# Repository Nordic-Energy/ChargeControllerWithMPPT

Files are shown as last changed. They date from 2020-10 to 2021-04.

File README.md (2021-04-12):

## Solar charge controller with MPPT algorithm

The charge controller is controlled by a dedicated STM32F334C8T6 microcontroller with a High Resolution PWM (HRPWM) on board. The use of this device is possible a devkit for studying the algorithms for finding the maximum power point (TMM) and as a device for working in an solar power plant with a capacity of up to 500 W.

Photo of MPPT

>

Photo of MPPT

When developing a charge controller the main emphasis is on creating reliable hardware using the best components and on implementing the most efficient TMM search algorithms. There are no electrolytic capacitors in the controller, instead of them solid polymer capacitors with an increased service life are used and as well as the thermal modes of operation of the device are optimized. That together will provide a guaranteed service life of at least 10 years. This will increase the reliability of autonomous mini-power plants and reduce equipment maintenance costs.

## Features:

* Use 32-bit ARM MCU STM32F334C8 with HRPWM
* Voltage input: *15...60V*
* Voltage output: *12/24V*
* Max charge current: *20A*
* Conversion frequency: *100kHz*
* Efficiency: *>94%*
* MPPT algorithm
* Type battery: *SLA, AGM, GEL, Li-ion, LiFePo4, LTO*
* Interface: *CAN, Wi-Fi*

## Built-in protection:
* Overvoltage
* Undervoltage
* Overcurrent
* Overheat
* PV short circuit
* PV reverse polarity
* Battery reverse polarity

## Project structure:

* *docs* - documentation for project: ВОМ, schematic, etc
* *hardware* - source project for design PCB
* *manufacture* - gerber files for order PCB
* *mechanical* - source project for 3D design

## Firmware

* [Universal firmware project for MPPT solar charge](https://github.com/RedCommissary/mppt-charger-firmware)
* [Project HMI TFT display panel for controller](https://github.com/RedCommissary/display-tft-3.5)

## License

All source files for the project are distributed under the [MIT](./LICENSE "Text license") license and you can use the project for commercial activities. But you need remembering that the author of the project does not give any guarantees for the operability of the device or parts of the project and also does not bear no liability for claims or damages.

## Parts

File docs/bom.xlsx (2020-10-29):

Designator | Value | PartNumber | Manufacturer | Quantity | Comment | HelpURL
C1, C6, C11, C14, C15, C22, C28, C34, C36, C38, C39, C40, C41, C44, C45, C49 | 0.1μF | CL10B104KB8WPND | Samsung | 16 | Ceramic capacitor, 0.1μF, X7R, ±10%, 50V, 603, -55...+125°C | https://www.digikey.com/product-detail/en/samsung-electro-mechanics/CL10B104KB8WPND/1276-CL10B104KB8WPNDCT-ND/11488014
C2 | 2.7pF | CL10C2R7CB81PNC | Samsung | 1 | Ceramic capacitor, 2.7pF, NPO, ±0.25pF, 50V, 603, -55...+125°C | https://www.digikey.com/product-detail/en/samsung-electro-mechanics/CL10C2R7CB81PNC/1276-6554-1-ND/5961413
C3 | 4.7pF | CL10C4R7BB8NNNC | Samsung | 1 | Ceramic capacitor, 4.7pF, NPO, ±0.1pF, 50V, 603, -55...+125°C | https://www.digikey.com/product-detail/en/samsung-electro-mechanics/CL10C4R7BB8NNNC/1276-1792-1-ND/3889878
C4, C5, C13, C35, C37, C43 | 4.7μF | CL10B475KQ8NQNC | Samsung | 6 | Ceramic capacitor, 4.7μF, X7R, ±10%, 6.3V, 603, -55...+125°C | https://www.digikey.com/en/products/detail/samsung-electro-mechanics/CL10B475KQ8NQNC/3887745
C7, C23, C29, C31, C33, C42 | 0.01μF | CL10B103KB8NNNC | Samsung | 6 | Ceramic capacitor, 0.01μF, X7R, ±10%, 50V, 603, -55...+125°C | https://www.digikey.com/product-detail/en/samsung-electro-mechanics/CL10B103KB8NNNC/1276-1009-1-ND/3889095
C8 | 2.2μF | CL32B225KCJSNNE | Samsung | 1 | Ceramic capacitor, 2.2μF, X7R, ±10%, 100V, 1210, -55...+125°C | https://www.digikey.com/en/products/detail/samsung-electro-mechanics/CL32B225KCJSNNE/3889020
C9, C12, C48 | 1μF | CL10B105KA8NNNC | Samsung | 3 | Ceramic capacitor, 1μF, X7R, ±10%, 25V, 603, -55...+125°C | https://www.digikey.com/product-detail/en/samsung-electro-mechanics/CL10B105KA8NNNC/1276-1184-1-ND/3889270
C10 | 22μF | CL32B226KOJNNNE | Samsung | 1 | Ceramic capacitor, 22μF, X7R, ±10%, 16V, 1210, -55...+125°C | https://www.digikey.com/en/products/detail/samsung-electro-mechanics/CL32B226KOJNNNE/3887513
C16 | 0.47μF | CL21B474KAFNNNG | Samsung | 1 | Ceramic capacitor, 0.47μF, X7R, ±10%, 25V, 805, -55...+125°C | https://www.digikey.com/product-detail/en/samsung-electro-mechanics/CL21B474KAFNNNG/1276-6480-1-ND/5958108
C17 | 2.2μF | CL21B225KAFNFNE | Samsung | 1 | Ceramic capacitor, 2.2μF, X7R, ±10%, 25V, 805, -55...+125°C | https://www.digikey.com/product-detail/en/samsung-electro-mechanics/CL21B225KAFNFNE/1276-2953-1-ND/3891039
C18, C19, C20, C21 | 330μF | 35SEK330M | Panasonic | 4 | Solid polymer capacitor, 330μF, 35V, ±20%, 18mOhm, 13x10x5 mm, -55...+105°C | https://www.digikey.com/product-detail/en/panasonic-electronic-components/35SEK330M/P122629-ND/8030545
C24, C25, C26, C27 | 68μF | 63SXE68M | Panasonic | 4 | Solid polymer capacitor, 68μF, 63V, ±20%, 25mOhm, 13x10x5 mm, -55...+105°C | https://www.digikey.com/products/en?keywords=63SXE68M
C30, C32 | 220pF | CL10B221KB8NFNC | Samsung | 2 | Ceramic capacitor, 220pF, X7R, ±10%, 50V, 603, -55...+125°C | https://www.digikey.com/product-detail/en/samsung-electro-mechanics/CL10B221KB8NFNC/1276-1986-1-ND/3890072
C46, C47 | 12pF | CL10C120JB8NNNC | Samsung | 2 | Ceramic capacitor, 12pF, NPO, ±10%, 50V, 603, -55...+125°C | https://www.digikey.com/product-detail/en/samsung-electro-mechanics/CL10C120JB8NNNC/1276-1254-1-ND/3889340
D1 |  | ESP32-PICO-D4 | Espressif Systems | 1 | IC RF transceiver, 802.11b/g/n + Bluetooth v4.2, 2.4GHz, 32-Bit, Xtensa LX6, 4Mb, 520KB, 2.7...3.6V, -40...+85°C, 48-LGA | https://www.digikey.com/product-detail/en/espressif-systems/ESP32-PICO-D4/1904-1029-1-ND/9381738
D2 |  | LM5017SD/NOPB | Texas Instruments | 1 | DC/DC buck converter, input 7.5...100V, 1MHz, output 1.225...90V, 0.6A, -40...+125°C, 8-WSON | https://www.digikey.com/product-detail/en/texas-instruments/LM5017SD-NOPB/LM5017SD-NOPBCT-ND/3137455
D3 |  | AP63200WU-7 | Diodes | 1 | DC/DC buck converter, input 3.8...32V, 500kHz, output 1.2...12V, 2A, -40...+85°C, SOT23-6 | https://www.digikey.com/en/products/detail/diodes-incorporated/AP63200WU-7/9858423
D4 |  | NCP5183DR2G | ON Semiconductor | 1 | Half-bridge gate driver, 600V, 500kHz, ±4.3A, supply 9...18V, -40...+125°C, 8-SOIC | https://www.digikey.com/product-detail/en/on-semiconductor/NCP5183DR2G/NCP5183DR2GOSCT-ND/7066807
D5, D6 |  | TSV991ILT | STMicroelectronics | 2 | IC op amplifier, Rail-to-Rail, 20 MHz, 2.7...5.5V, -40...+125°C, SOT23-5 | https://www.digikey.com/product-detail/en/stmicroelectronics/TSV991ILT/497-6001-1-ND/1578484
D7 |  | STM32F334C4T6 | STMicroelectronics | 1 | IC microcontroller, 32-Bit, Cortex-M4, 72MHz, 16KB, 12KB, 2...3.6V, -40...+85°C, 48-LQFP | https://www.digikey.com/en/products/detail/stmicroelectronics/STM32F334C4T6/4989170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
D8 |  | 24AA01T-I/OT | Microchip Technology | 1 | IC memory, EEPROM, 1KB (128x8), 400 kHz, I2C, 1.7...5.5V, -40...+85°C, SOT-23-5 | https://www.digikey.com/product-detail/en/microchip-technology/24AA01T-I-OT/24AA01T-I-OTCT-ND/857670
D9 |  | SN65HVD231DR | Texas Instruments | 1 | IC CAN transceiver, 1Mbps, Half-duplex, 3...3.6V, -40...+85°C, 8-SOIC | https://www.digikey.com/product-detail/en/texas-instruments/SN65HVD231DR/296-26343-1-ND/2254977
L1 | 1.6nH | LQW18AS1N6J0ZD | Murata Electronics | 1 | Fixed inductor, 1.6nH, ±5%, 603, 700mA, -55...+125°C | https://www.digikey.com/product-detail/en/murata-electronics/LQW18AS1N6J0ZD/490-15806-1-ND/6800471
L2 | 220μH | SDR0805-221KL | Bourns | 1 | Fixed inductor, 220μH, ±10%, SDR0805, 490mA, -40...+125°C | https://www.digikey.com/product-detail/en/bourns-inc/SDR0805-221KL/SDR0805-221KLCT-ND/2127164
L3 | 4.7μH | CD32YP0302-4R7M | YJYCOIN | 1 | Fixed inductor, 4.7μH, ±20%, CD32 series, 1.5A, -40...+125°C | https://lcsc.com/product-detail/New-Arrivals_YJYCOIN-CD32YP0302-4R7M_C492259.html
L4 | 40μH | 0077548A7 | Magnetics | 1 | Fixed inductor, 40μH, ±10%, R32.8/20.1/10.7, Kool Mu, µ=125, 127 нГн/витков2 | http://ferrite.ru/warehouse/r-32-820-110-7-77548-a7.html
L5 | 10μH | LQM18FN100M00D | Murata Electronics | 1 | Fixed inductor, 10μH, ±20%, 603, 50mA, -55...+125°C | https://www.digikey.com/product-detail/en/murata-electronics-north-america/LQM18FN100M00D/490-4025-1-ND/1016285
R1, R2, R5, R8, R9, R12, R16, R17, R21, R22, R24, R28, R33, R34, R48, R50, R52 | 10k | AC0603FR-0710KL | Yageo | 17 | Resistor film, 10k, ±1%, 603, 0.1W, -55...+125°C | https://www.digikey.com/en/products/detail/yageo/AC0603FR-0710KL/2827814
R3 | 499k | RC0603FR-07499KL | Yageo | 1 | Resistor film, 499k, ±1%, 603, 0.1W, -55...+125°C | https://www.digikey.com/en/products/detail/yageo/RC0603FR-07499KL/727267
R4 | 91k | RC0603FR-0791KL | Yageo | 1 | Resistor film, 91k, ±1%, 603, 0.1W, -55...+125°C | https://www.digikey.com/en/products/detail/yageo/RC0603FR-0791KL/727428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
R6, R31, R32, R37, R40, R43, R45, R46, R47, R54, R55, R57, R58, R60, R61, R63, R64 | 1k | RC0603FR-071KL | Yageo | 17 | Resistor film, 1k, ±1%, 603, 0.1W, -55...+125°C | https://www.digikey.com/product-detail/en/yageo/RC0603FR-071KL/311-1-00KHRCT-ND/729790
R7 | 88k7 | RC0603FR-0788K7L | Yageo | 1 | Resistor film, 88k7, ±1%, 603, 0.1W, -55...+125°C | https://www.digikey.com/en/products/detail/yageo/RC0603FR-0788K7L/727415
R11 | 30k9 | RC0603FR-0730K9L | Yageo | 1 | Resistor film, 30k9, ±1%, 603, 0.1W, -55...+125°C | https://www.digikey.com/en/products/detail/yageo/RC0603FR-0730K9L/727144
R13, R15 | 2R4 | RC0805JR-072R4L | Yageo | 2 | Resistor film, 2R4, ±5%, 805, 0.125W, -55...+125°C | https://www.digikey.com/product-detail/en/yageo/RC0805JR-072R4L/311-2.4ARCT-ND/731220
R14, R19, R26 | 10k | RC0805JR-0710KL | Yageo | 3 | Resistor film, 10k, ±5%, 805, 0.125W, -55...+125°C | https://www.digikey.com/product-detail/en/yageo/RC0805JR-0710KL/311-10KARCT-ND/731188
R18 | 39k | RC0603FR-0739KL | Yageo | 1 | Resistor film, 39k, ±1%, 603, 0.1W, -55...+125°C | https://www.digikey.com/en/products/detail/yageo/RC0603FR-0739KL/727195
R20, R23, R27, R35, R41, R49, R51, R53, R56, R59, R62 | 120R | RC0603JR-07120RL | Yageo | 11 | Resistor film, 120R, ±5%, 603, 0.1W, -55...+125°C | https://www.digikey.com/product-detail/en/yageo/RC0603JR-07120RL/311-120GRCT-ND/729653
R25 | 100k | RC0805FR-07100KL | Yageo | 1 | Resistor film, 100k, ±1%, 805, 0.125W, -55...+125°C | https://www.digikey.com/product-detail/en/yageo/RC0805FR-07100KL/311-100KCRCT-ND/730491
R29 | 5k1 | RC0603FR-075K1L | Yageo | 1 | Resistor film, 5k1, ±1%, 603, 0.1W, -55...+125°C | https://www.digikey.com/en/products/detail/yageo/RC0603FR-075K1L/727268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
R30, R38, R39, R44 | 75k | AC0603FR-0775KL | Yageo | 4 | Resistor film, 75k, ±1%, 603, 0.1W, -55...+125°C | https://www.digikey.com/en/products/detail/yageo/AC0603FR-0775KL/5896284
R36, R42 | 0R002 | PA2512FKM7W0R002E | Yageo | 2 | Resistor film, 0R002, ±1%, 2512, 2W, -55...+170°C | https://www.digikey.com/en/products/detail/yageo/PA2512FKM7W0R002E/9696342
SB1 |  | PTS636 SM43 | C&K | 1 | Tactile button, 6x3.5mm | https://www.digikey.com/product-detail/en/c-k/PTS636-SM43-SMTR-LFS/CKN12310-1-ND/10071745
VD1, VD5 |  | MBR2H100SFT3G | ON Semiconductor | 2 | Schottky diode, 100V, 2A, 840mV, 15pF, SOD-123F, -55...+150°C | https://www.digikey.com/product-detail/en/on-semiconductor/MBR2H100SFT3G/MBR2H100SFT3GOSCT-ND/3462288
VD2, VD3, VD7 |  | 150060VS75000 | Wurth | 3 | LED, 20mA, 2V, 603, -55...+150°C | https://www.digikey.com/product-detail/en/w-rth-elektronik/150060VS75000/732-4980-1-ND/4489904
VD6 |  | MMSZ5245BT1G | ON Semiconductor | 1 | Zener diode, 16V, 500mW, 0.9V, 16Ohm, SOD-123, -55...+150°C | https://www.digikey.com/product-detail/en/on-semiconductor/MMSZ5245BT1G/MMSZ5245BT1GOSCT-ND/1139899
VD8, VD11, VD13, VD14, VD15 |  | 150060RS75000 | Wurth | 5 | LED, 20 mA, 2V, 603, -55...+150°C | https://www.digikey.com/product-detail/en/w-rth-elektronik/150060RS75000/732-4978-1-ND/4489899
VD9 |  | ESDCAN06-2BLY | STMicroelectronics | 1 | TVS diode, 24V, 230W peak, 3A, 13pF, SOT-23, -40...+150°C | https://www.digikey.com/product-detail/en/stmicroelectronics/ESDCAN06-2BLY/497-19090-1-ND/10057130
VD10 |  | 150060BS75000 | Wurth | 1 | LED, 20mA, 3.2V, 603, -55...+150°C | https://www.digikey.com/product-detail/en/w-rth-elektronik/150060BS75000/732-4966-1-ND/4489893
VD12 |  | 150060YS75000 | Wurth | 1 | LED, 20mA, 2V, 603, -55...+150°C | https://www.digikey.com/product-detail/en/wurth-electronics-inc/150060YS75000/732-4981-1-ND/4489907
VT1, VT2, VT4, VT6 |  | IPP086N10N3GXKSA1 | Infineon Technologies | 4 | MOSFET N-channel transistor, 100V, 80A, 55nC, 125W, 8.6mOhm, 3980pF, TO-220, -55...+150°C | https://www.digikey.com/en/products/detail/infineon-technologies/IPP086N10N3GXKSA1/2081155
VT3 |  | IRLML0030TRPBF | Infineon Technologies | 1 | MOSFET N-channel transistor, 30V, 5.3A, 2.6nC, 1.3W, 27mOhm, 382pF, SOT-23, -55...+150°C | https://www.digikey.com/product-detail/en/infineon-technologies/IRLML0030TRPBF/IRLML0030TRPBFCT-ND/2202231
VT5 |  | BSS315PH6327XTSA1 | Infineon Technologies | 1 | MOSFET P-channel transistor, 30V, 1.5A, 2.3nC, 500mW, 150mOhm, 282pF, SOT-23, -55...+150°C | https://www.digikey.com/en/products/detail/infineon-technologies/BSS315PH6327XTSA1/2783468
VT7 |  | BC847CLT1G | ON Semiconductor | 1 | NPN transistor, 45V, 100mA, 100MHz, 300mW, 0.6V, 420, SOT-23, -55...+125°C | https://www.digikey.com/product-detail/en/on-semiconductor/BC847CLT1G/BC847CLT1GOSCT-ND/917836
X1 |  | SM06B-GHS | JST | 1 | Connector, 6pin, 1.25mm, 50VDC, 1A | https://www.digikey.com/product-detail/en/jst-sales-america-inc/SM06B-GHS-TB-LF-SN/455-1568-1-ND/807836
X2 |  | U.FL-R-SMT(01) | Hirose Electric | 1 | Connector u.FL, 50 Ohm, 6GHz | https://www.digikey.com/product-detail/en/hirose-electric-co-ltd/U.FL-R-SMT-01/H9161-ND/513010
X3, X4 |  | XT60PW-M | AMASS | 2 | Power connector, 2pin, 7.2mm, 500V, 60A | https://lcsc.com/product-detail/Connectors_Changzhou-Amass-Elec-XT60PW-M_C98732.html
X5, X6 |  | CWF-2 | Connfly | 2 | Connector, 2pin, 2.54mm, 250VAC, 3A | https://www.chipdip.ru/product/cwf-2
X7 |  | SM05B-GHS | JST | 1 | Connector, 5pin, 1.25mm, 50VDC, 1A | https://www.digikey.com/product-detail/en/jst-sales-america-inc/SM05B-GHS-TB-LF-SN/455-1567-1-ND/807835
X8 |  | CWF-4 | Connfly | 1 | Connector, 4pin, 2.54mm, 250VAC, 3A | https://www.chipdip.ru/product/cwf-4
X9 |  | 615008137421 | Wurth | 1 | Etherner RJ-45 connector | https://www.digikey.com/product-detail/en/w-rth-elektronik/615008137421/732-2112-ND/2060608
Z1 |  | ECS-80-12-33-JGN-TR | ECS | 1 | Crystal, 8MHz, 12pF, ±30ppm, case 3225, -40...+85°C | https://www.digikey.com/product-detail/en/ecs-inc/ECS-80-12-33-JGN-TR/50-ECS-80-12-33-JGN-CT-ND/10478769

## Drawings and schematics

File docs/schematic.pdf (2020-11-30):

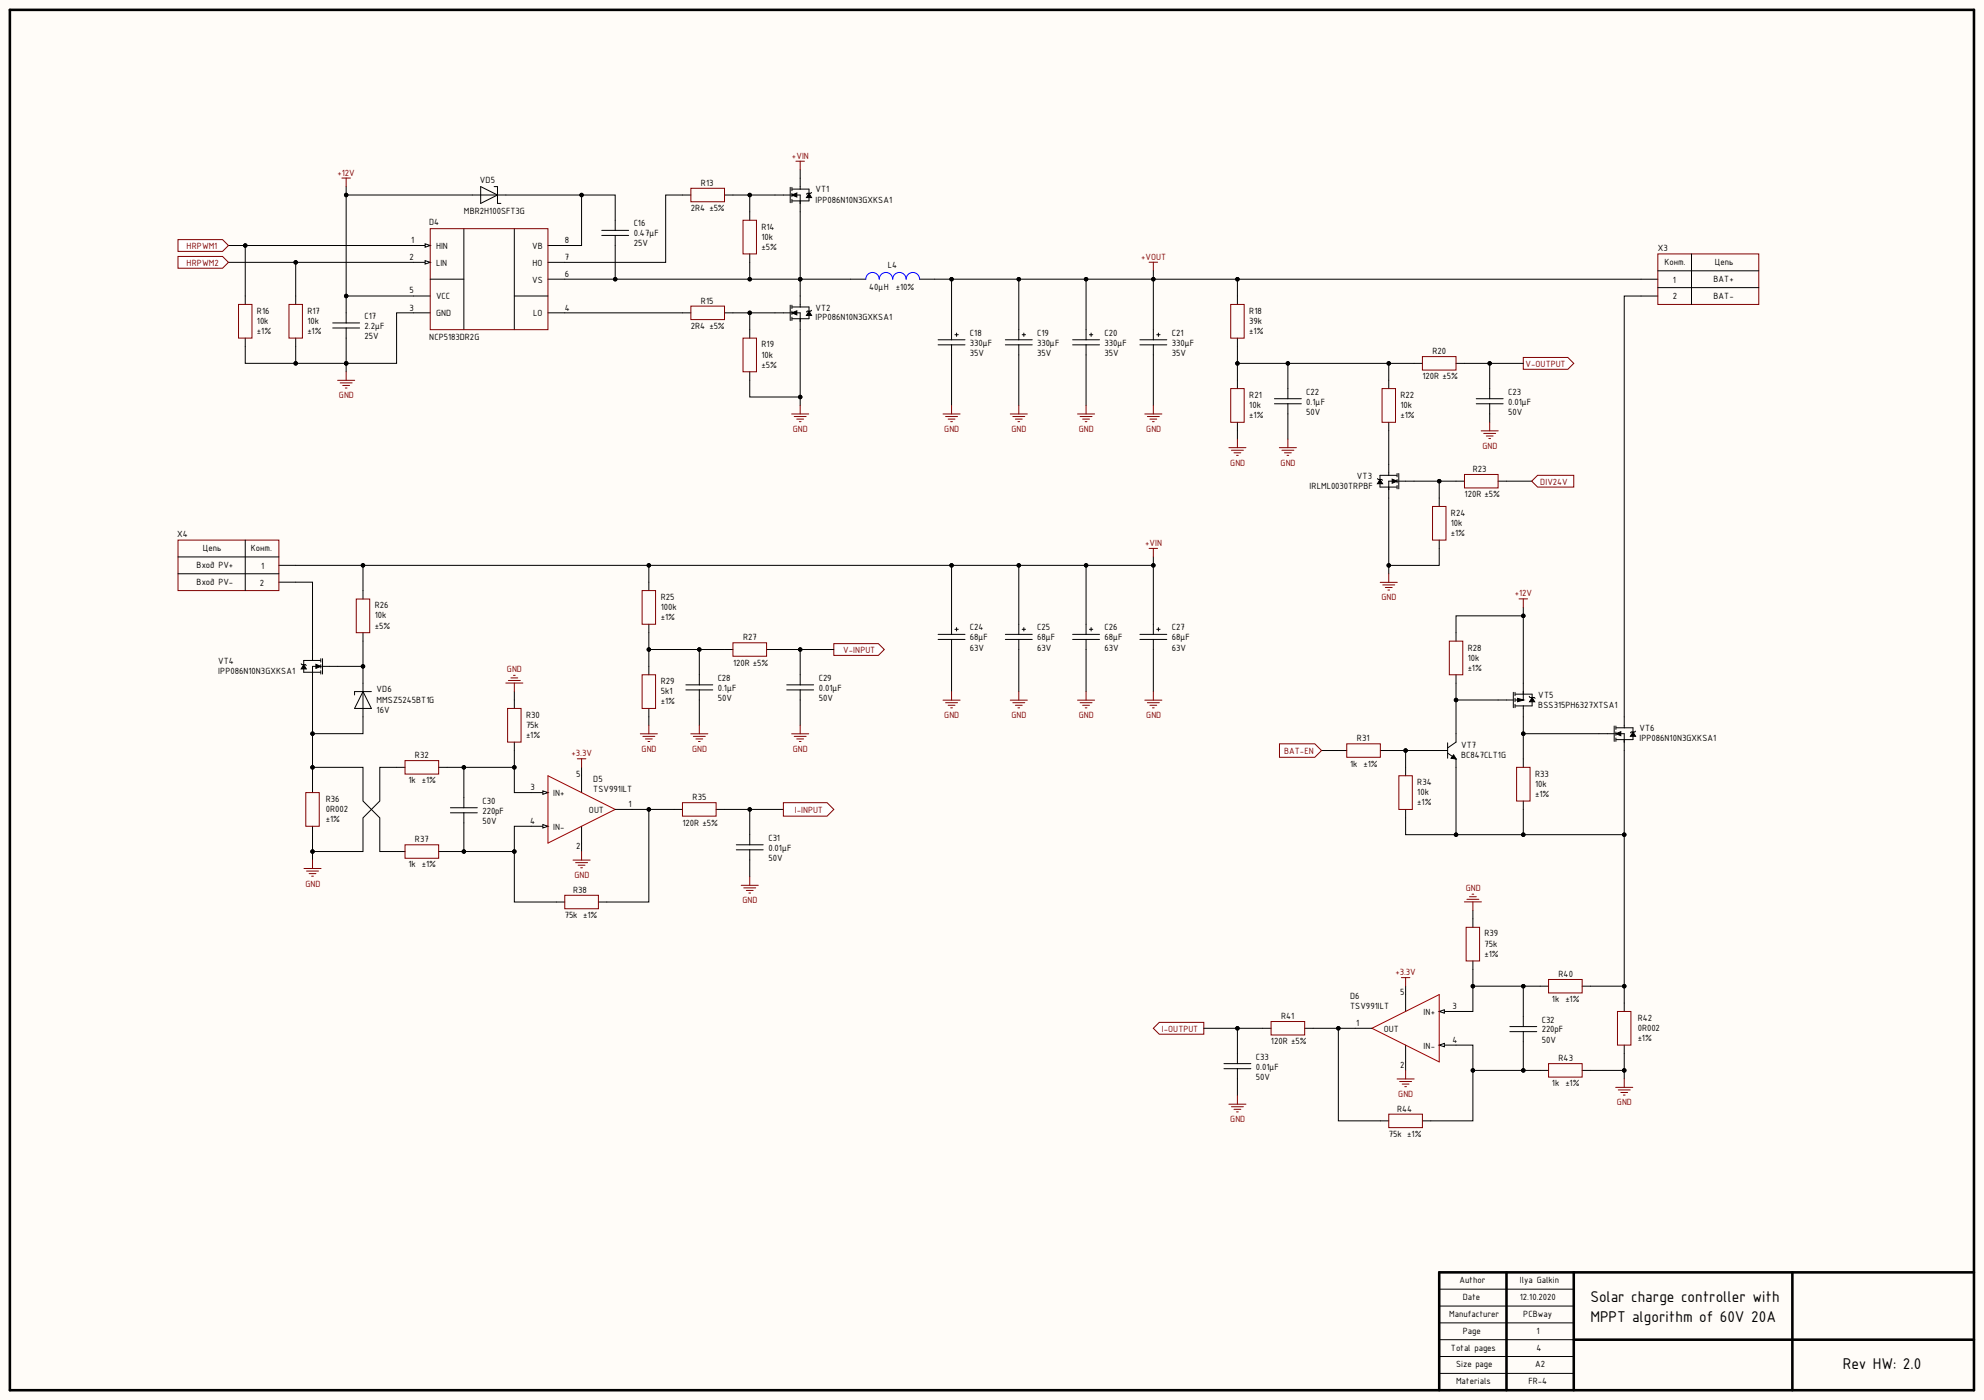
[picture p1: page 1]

Конт. | Цепь

1 | BAT+

2 | BAT-

Цепь | Конт.

Вход PV+ | 1

Вход PV- | 2

Author | Ilya Galkin | Solar charge controller with MPPT algorithm of 60V 20A

Date | 12.10.2020

Manufacturer | PCBway

Page

Total pages | | | Rev HW: 2.0

Size page | A2

Materials | FR-4

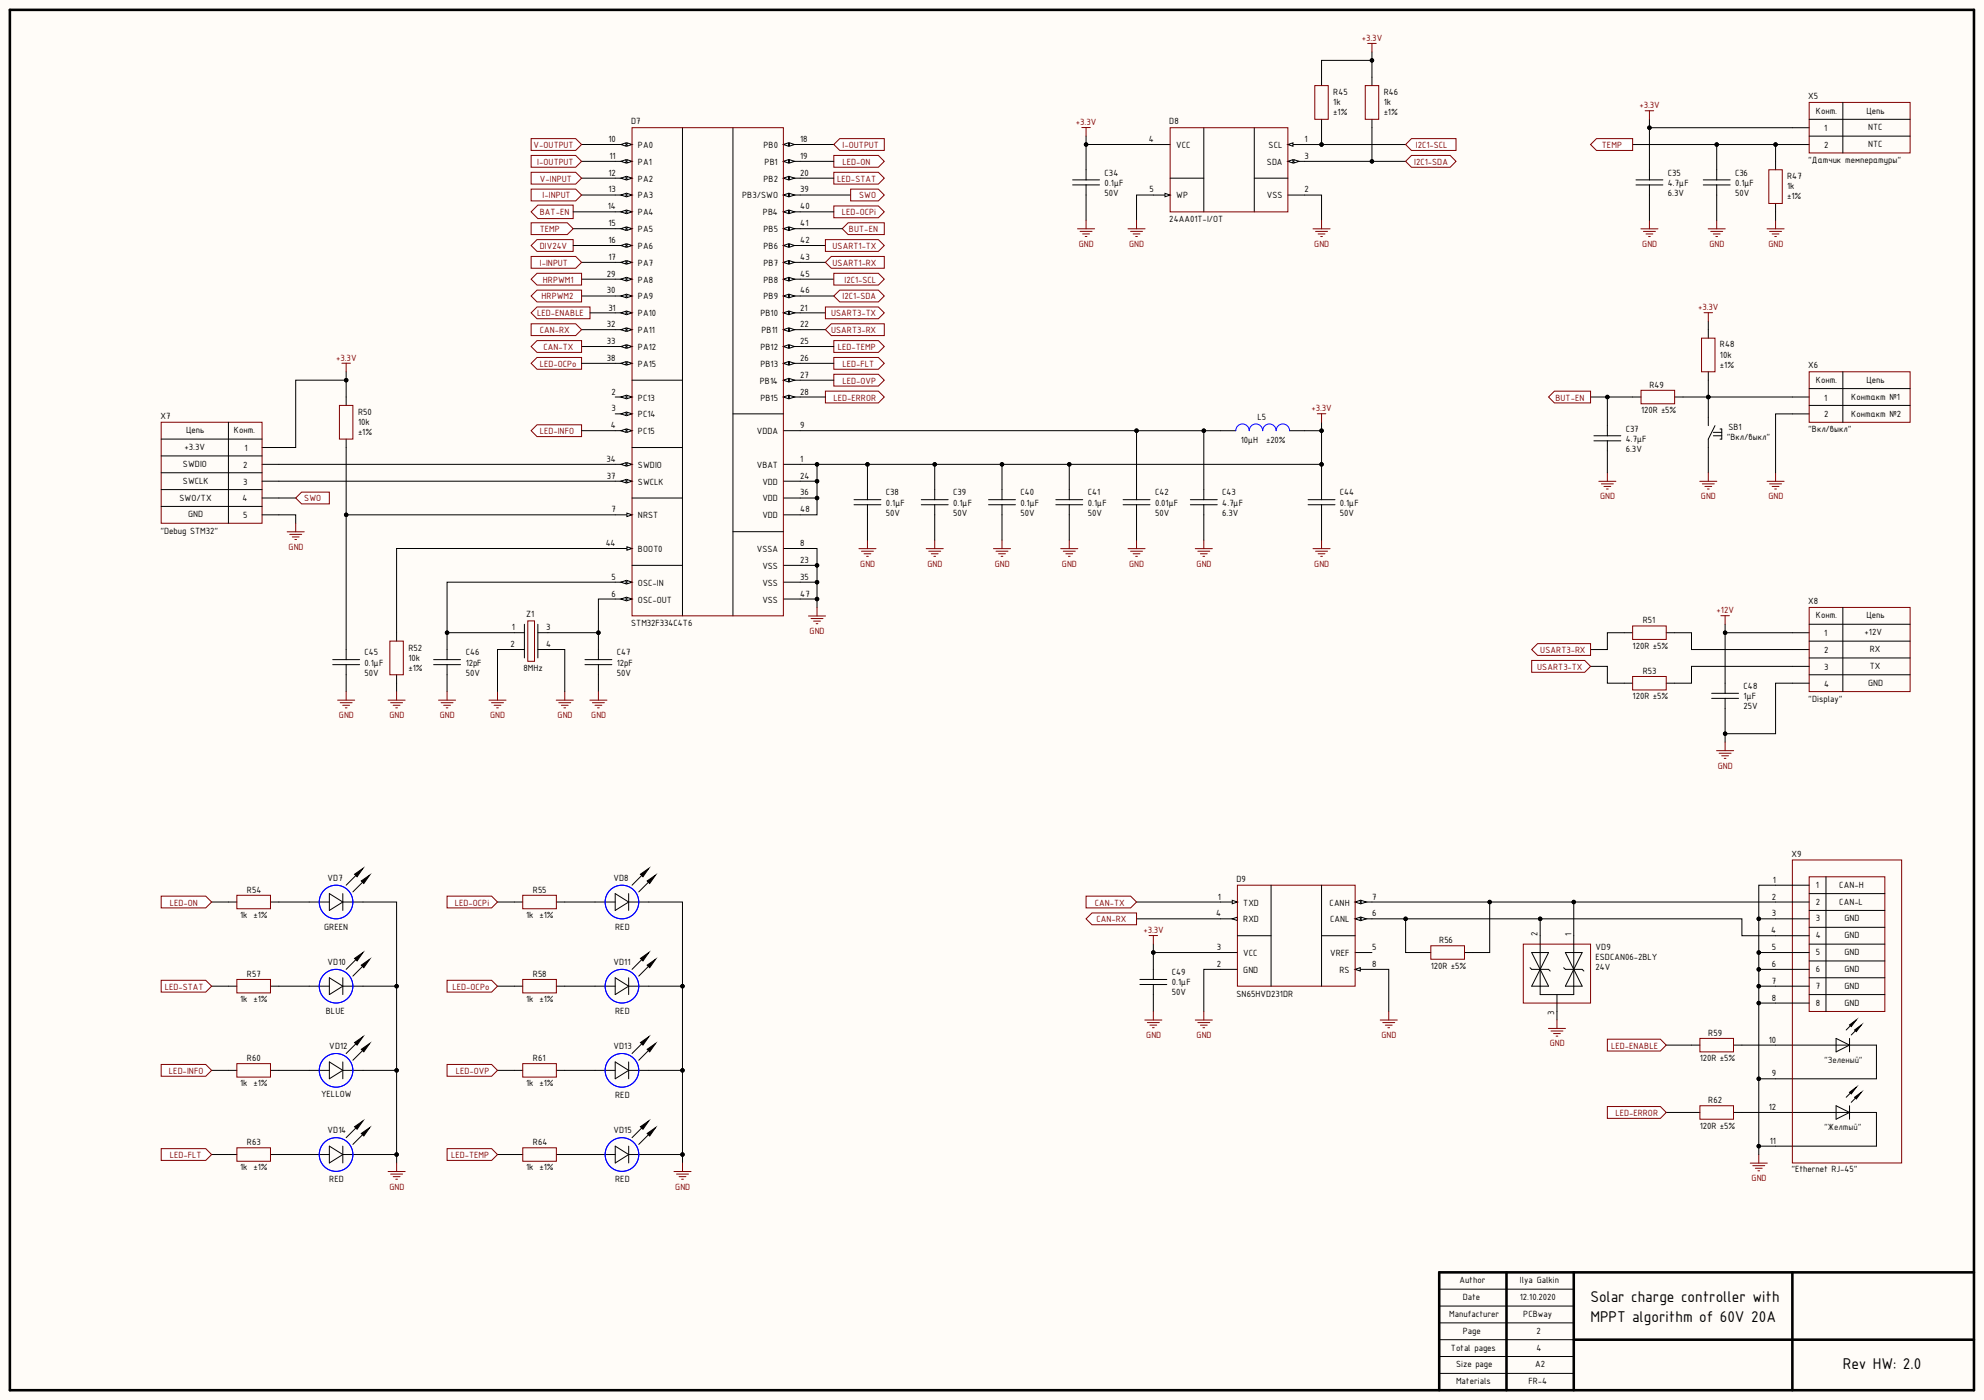
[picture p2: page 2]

Конт. | Цепь

1 | NTC

2 | NTC

1 | Контакт №1

2 | Контакт №2

Цепь | Конт.

SWDIO | 2

SWCLK | 3

4 | GND

CAN-H

2 | CAN-L

RXD 4 | 3

5 | GND

6 | GND

7 | GND

9 | "Зеленый"

Author | Ilya Galkin | Solar charge controller with MPPT algorithm of 60V 20A

Date | 12.10.2020

Manufacturer | PCBway

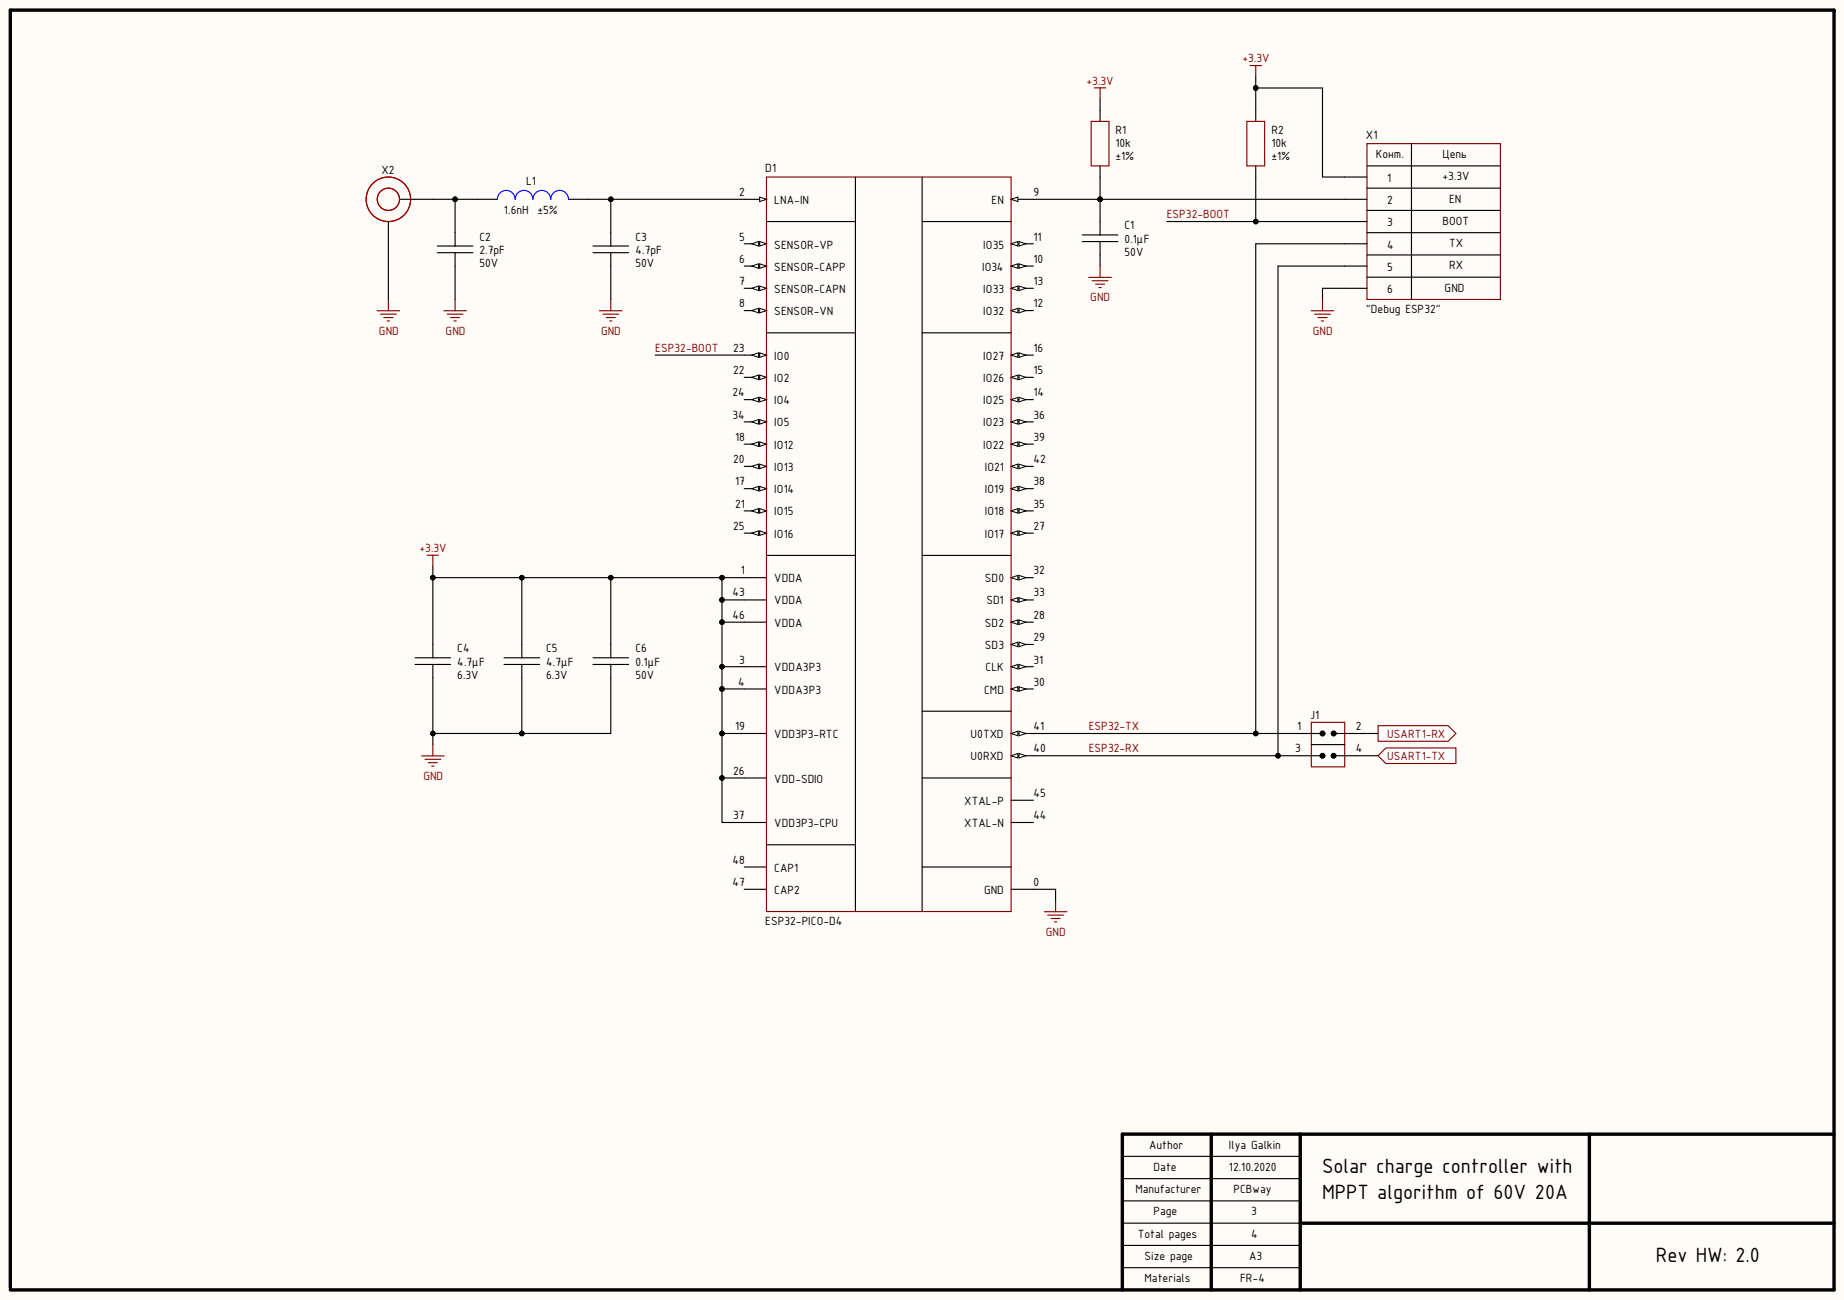
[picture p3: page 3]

Конт. | Цепь

3 | BOOT

6 | GND

VDDA 43

VDDA 46

VDDA3P3 3

VDDA3P3 4

VDD3P3-RTC 19

VDD-SDIO 26

Author | Ilya Galkin | Solar charge controller with MPPT algorithm of 60V 20A

Date | 12.10.2020

Manufacturer | PCBway

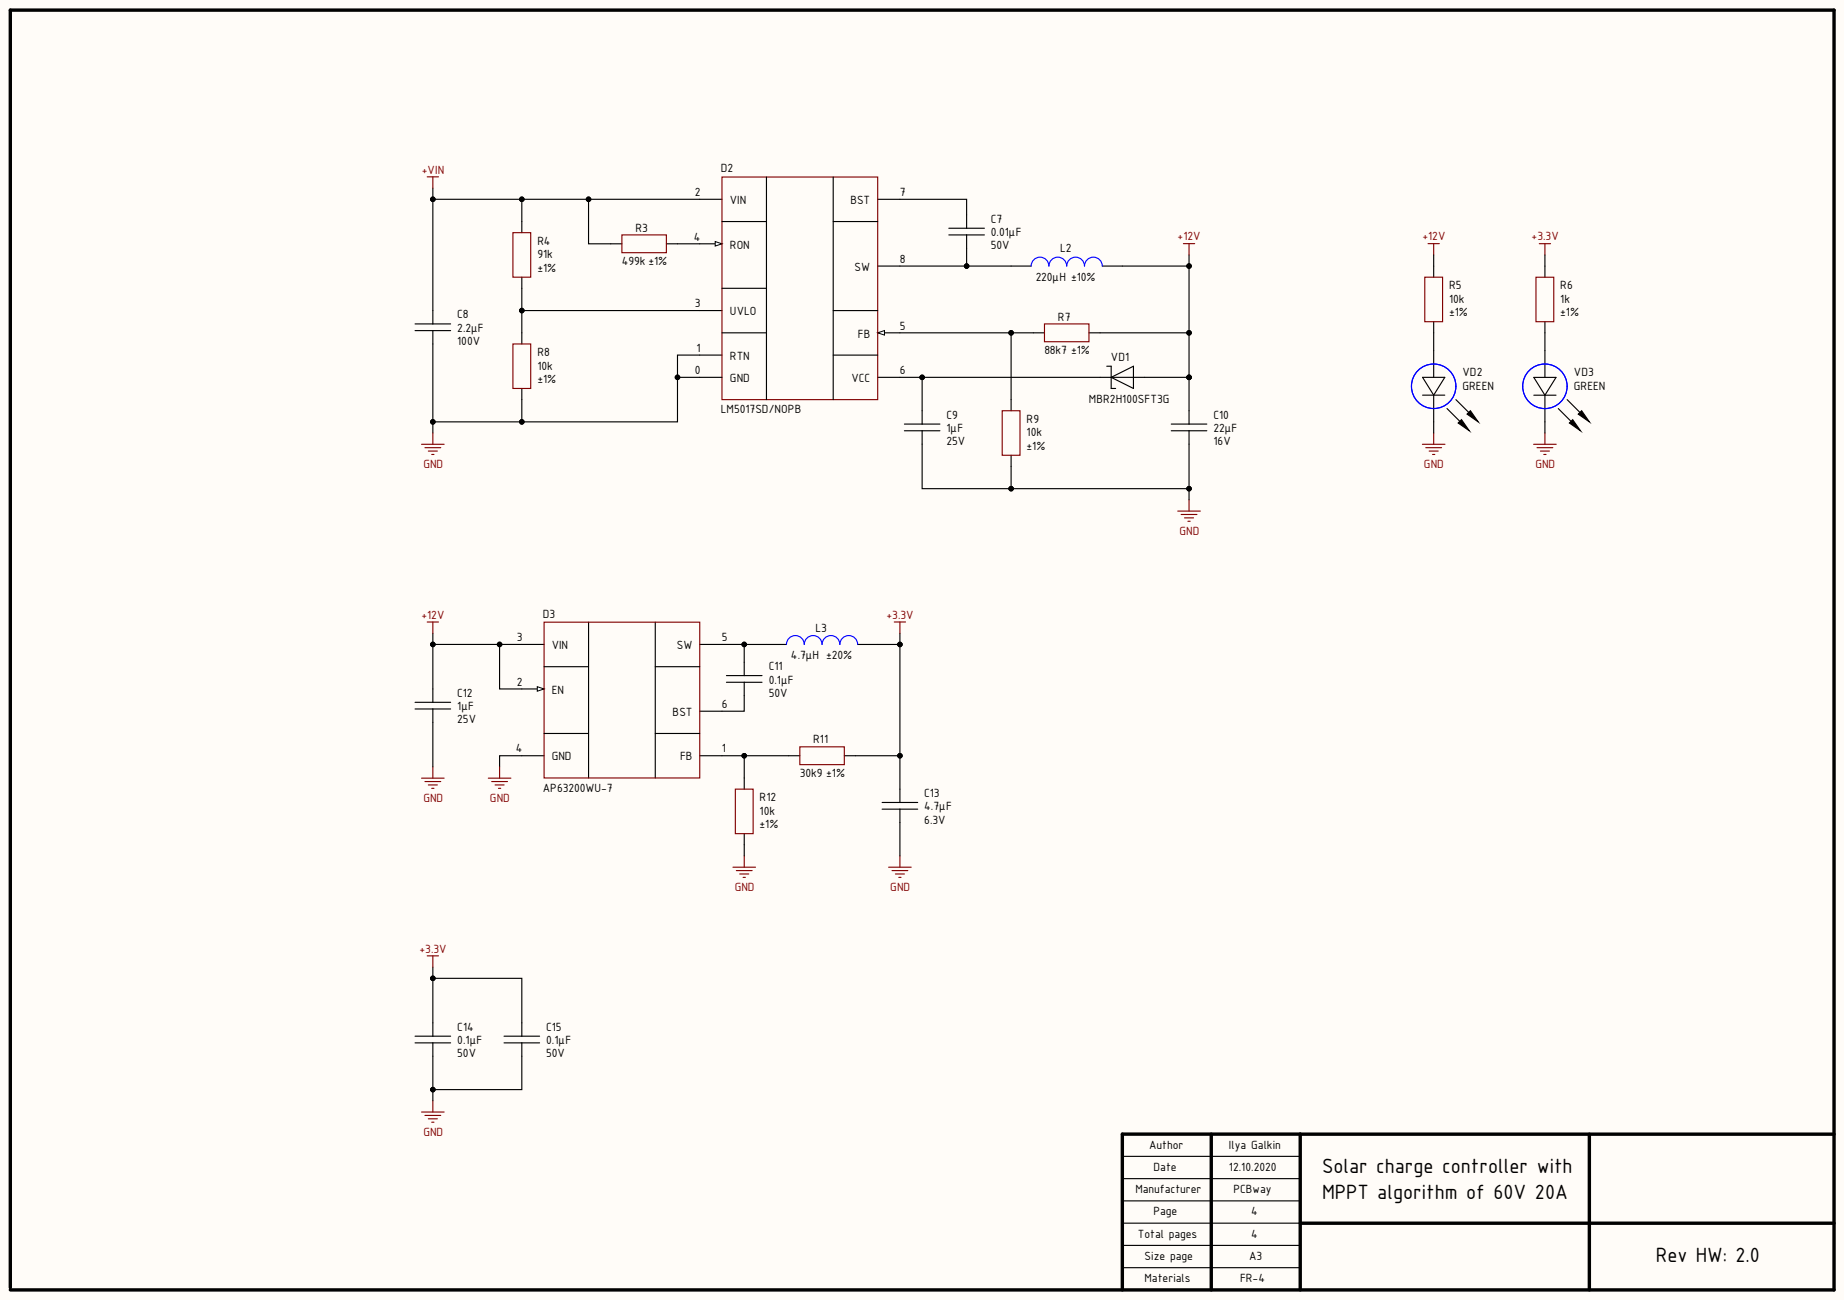
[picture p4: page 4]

Author | Ilya Galkin | Solar charge controller with MPPT algorithm of 60V 20A

Date | 12.10.2020

Manufacturer | PCBway

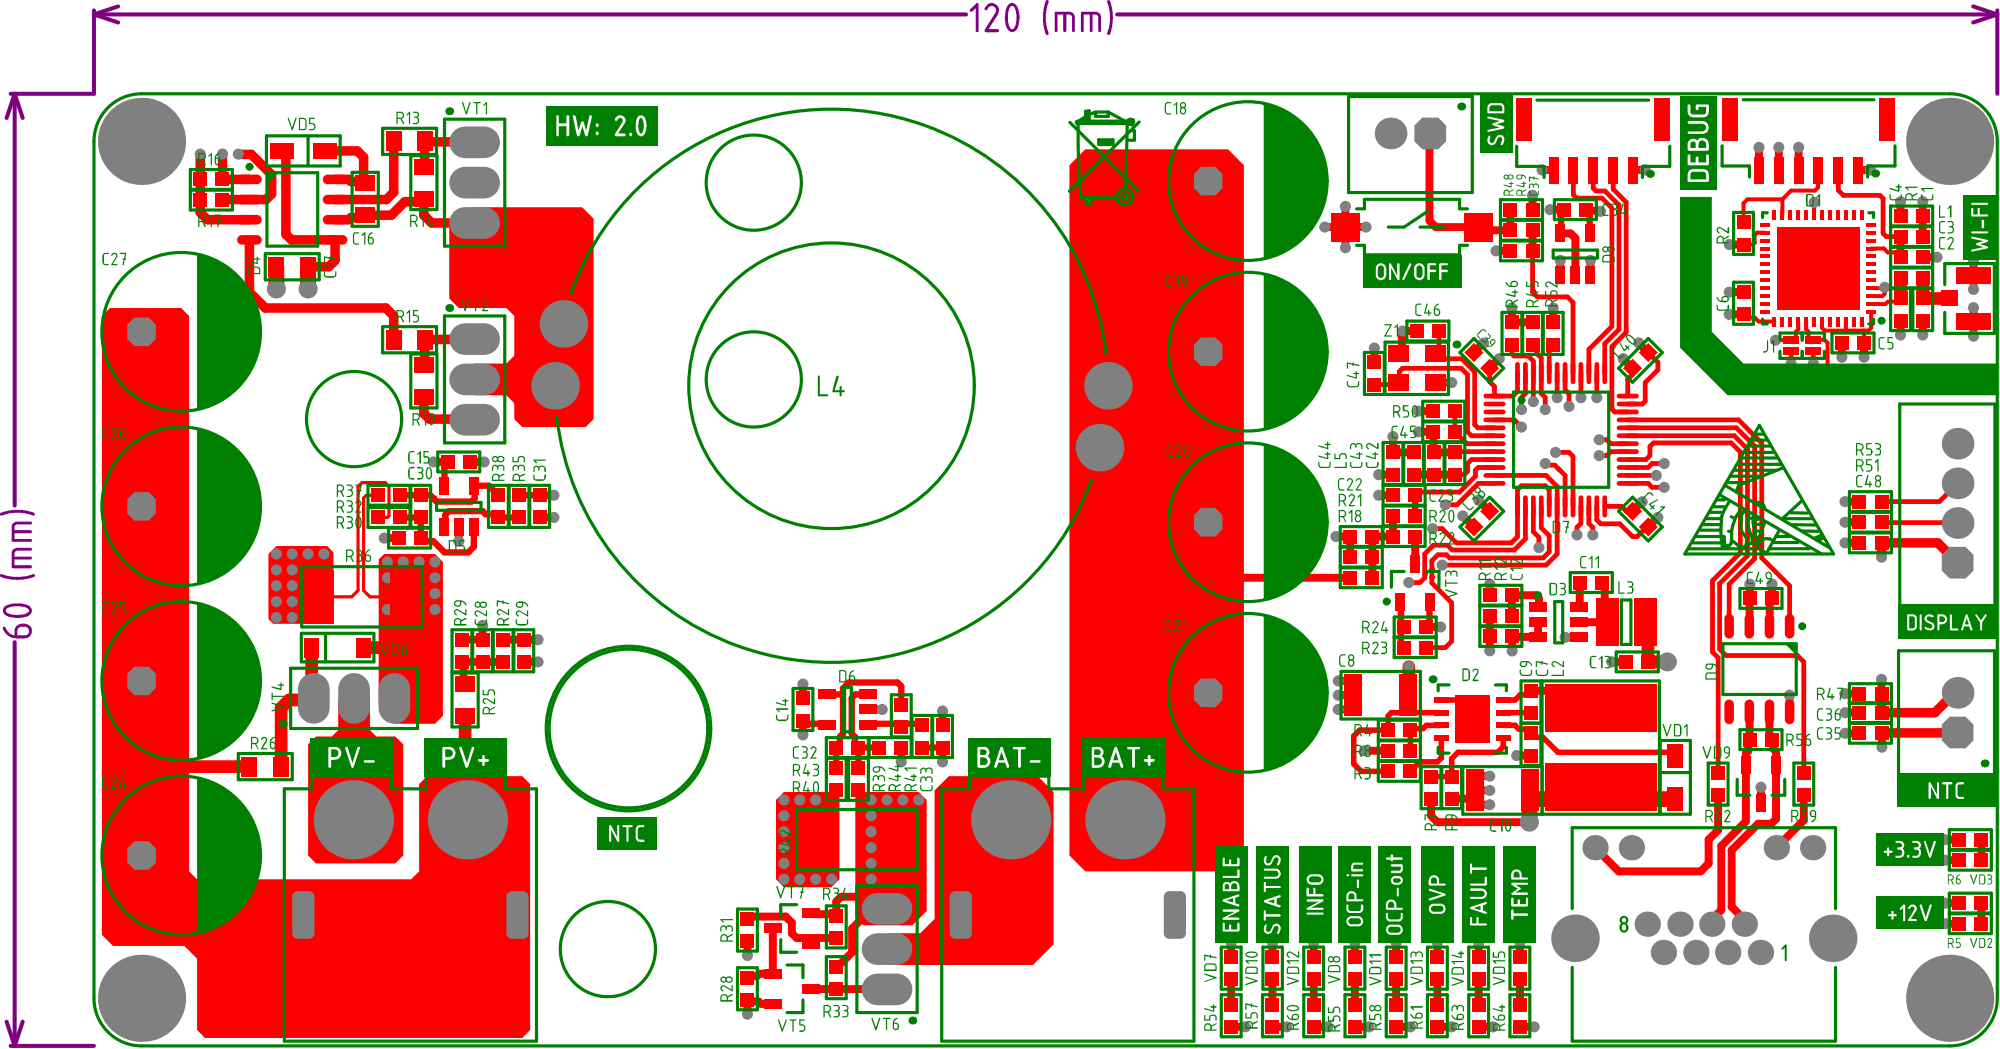
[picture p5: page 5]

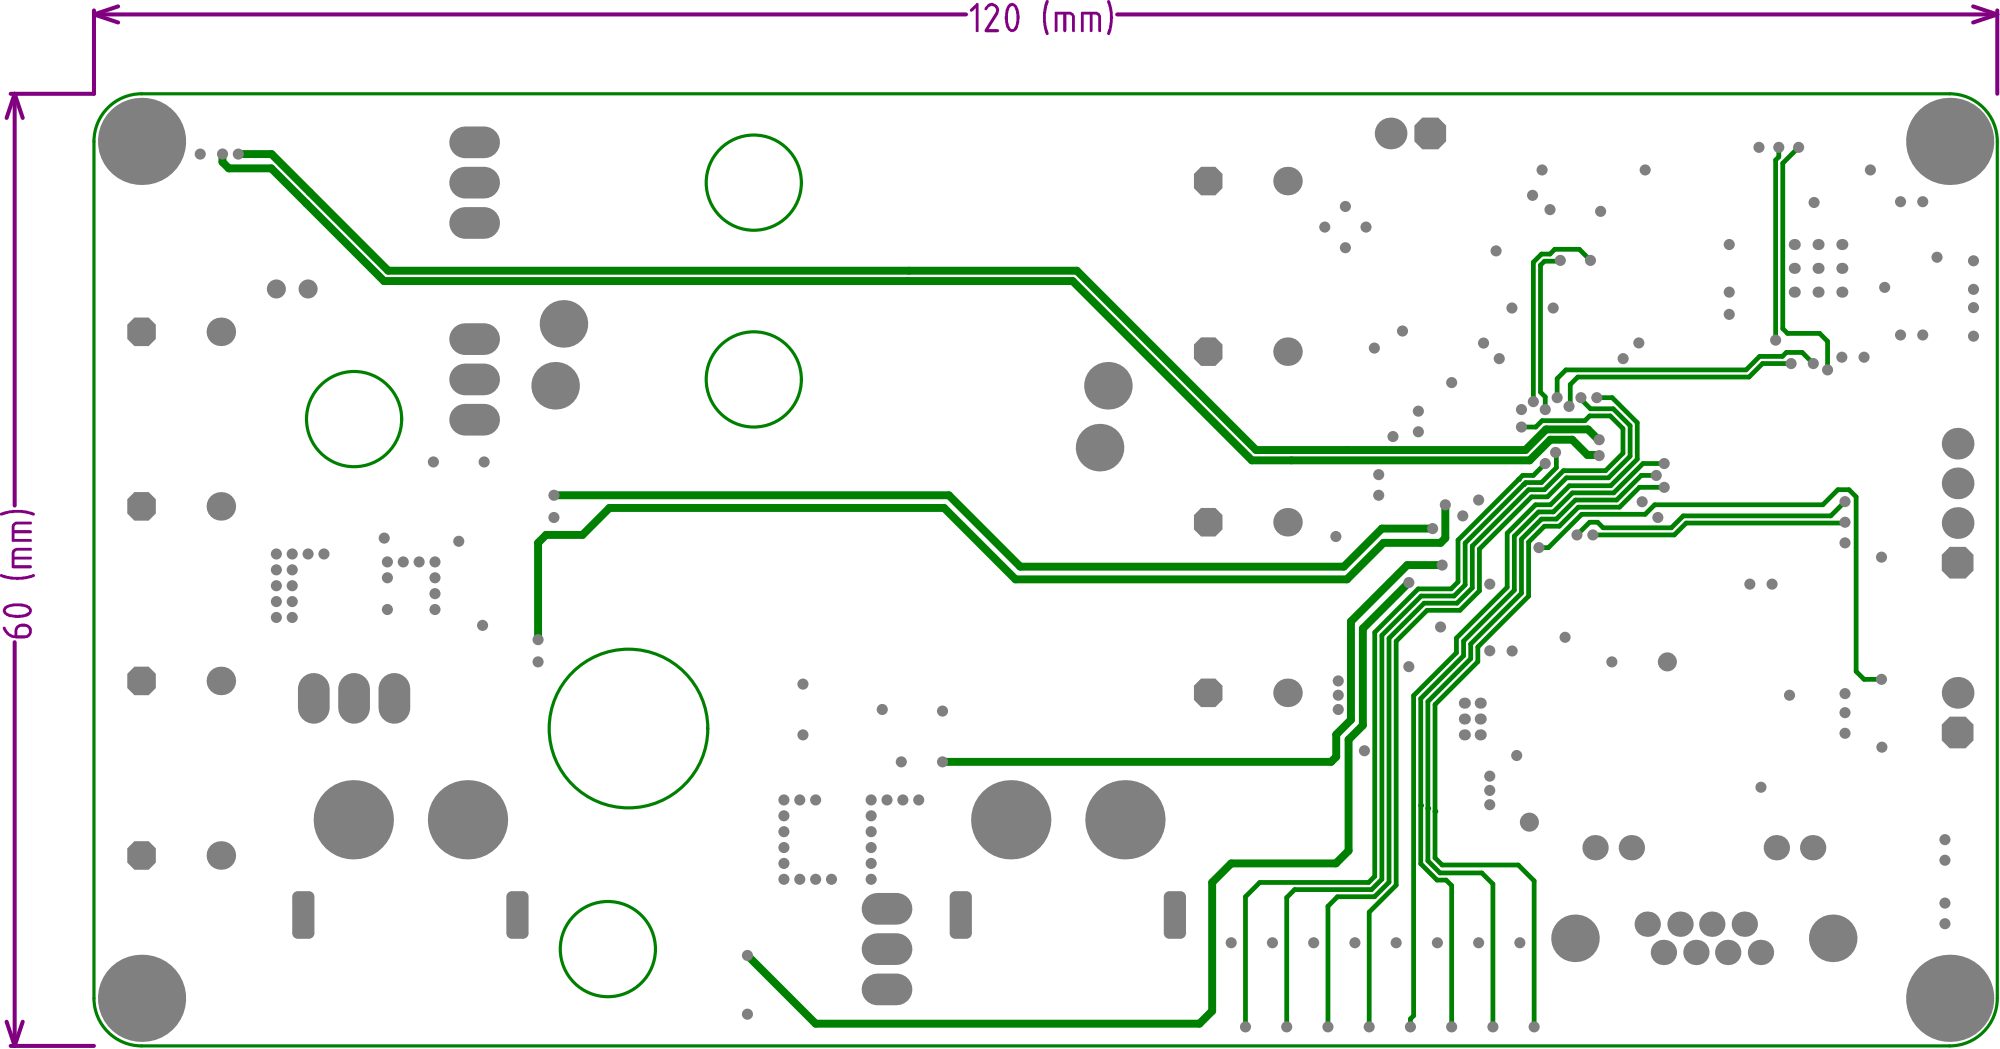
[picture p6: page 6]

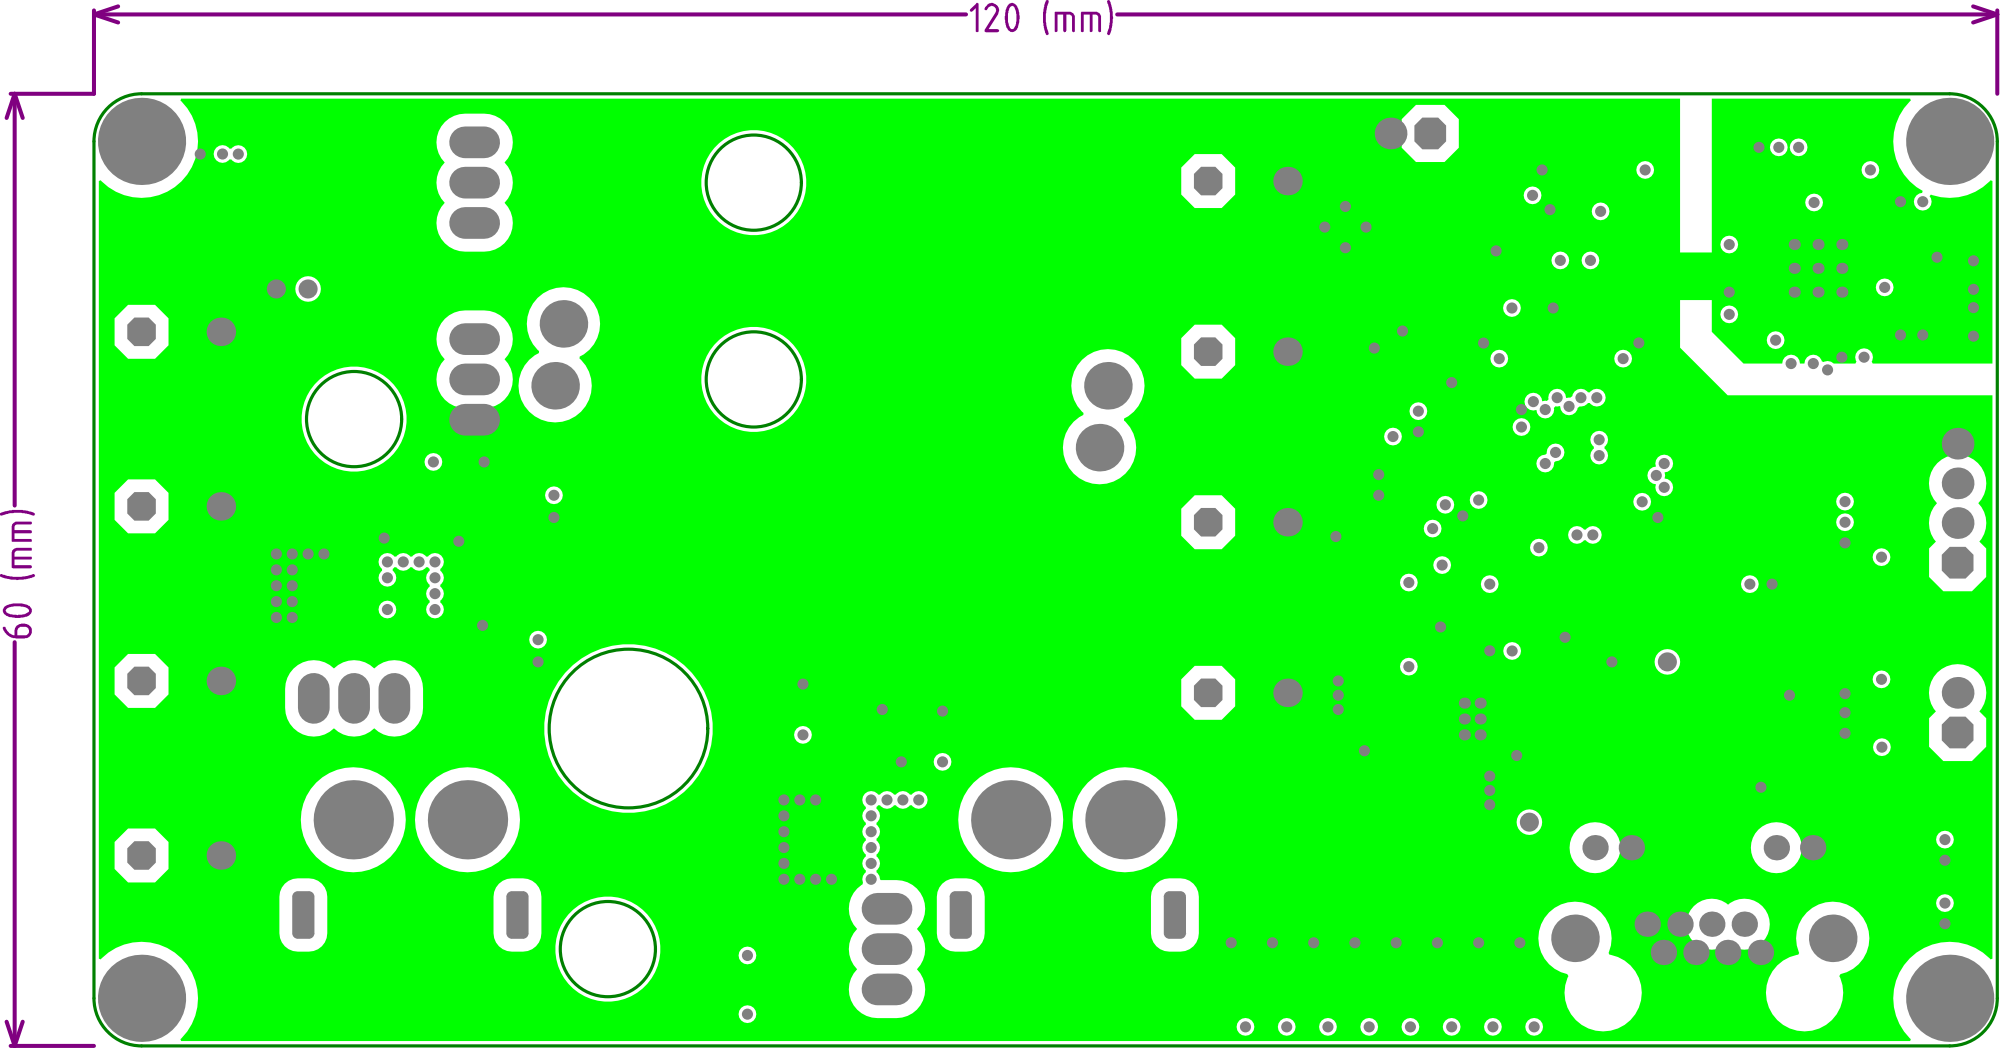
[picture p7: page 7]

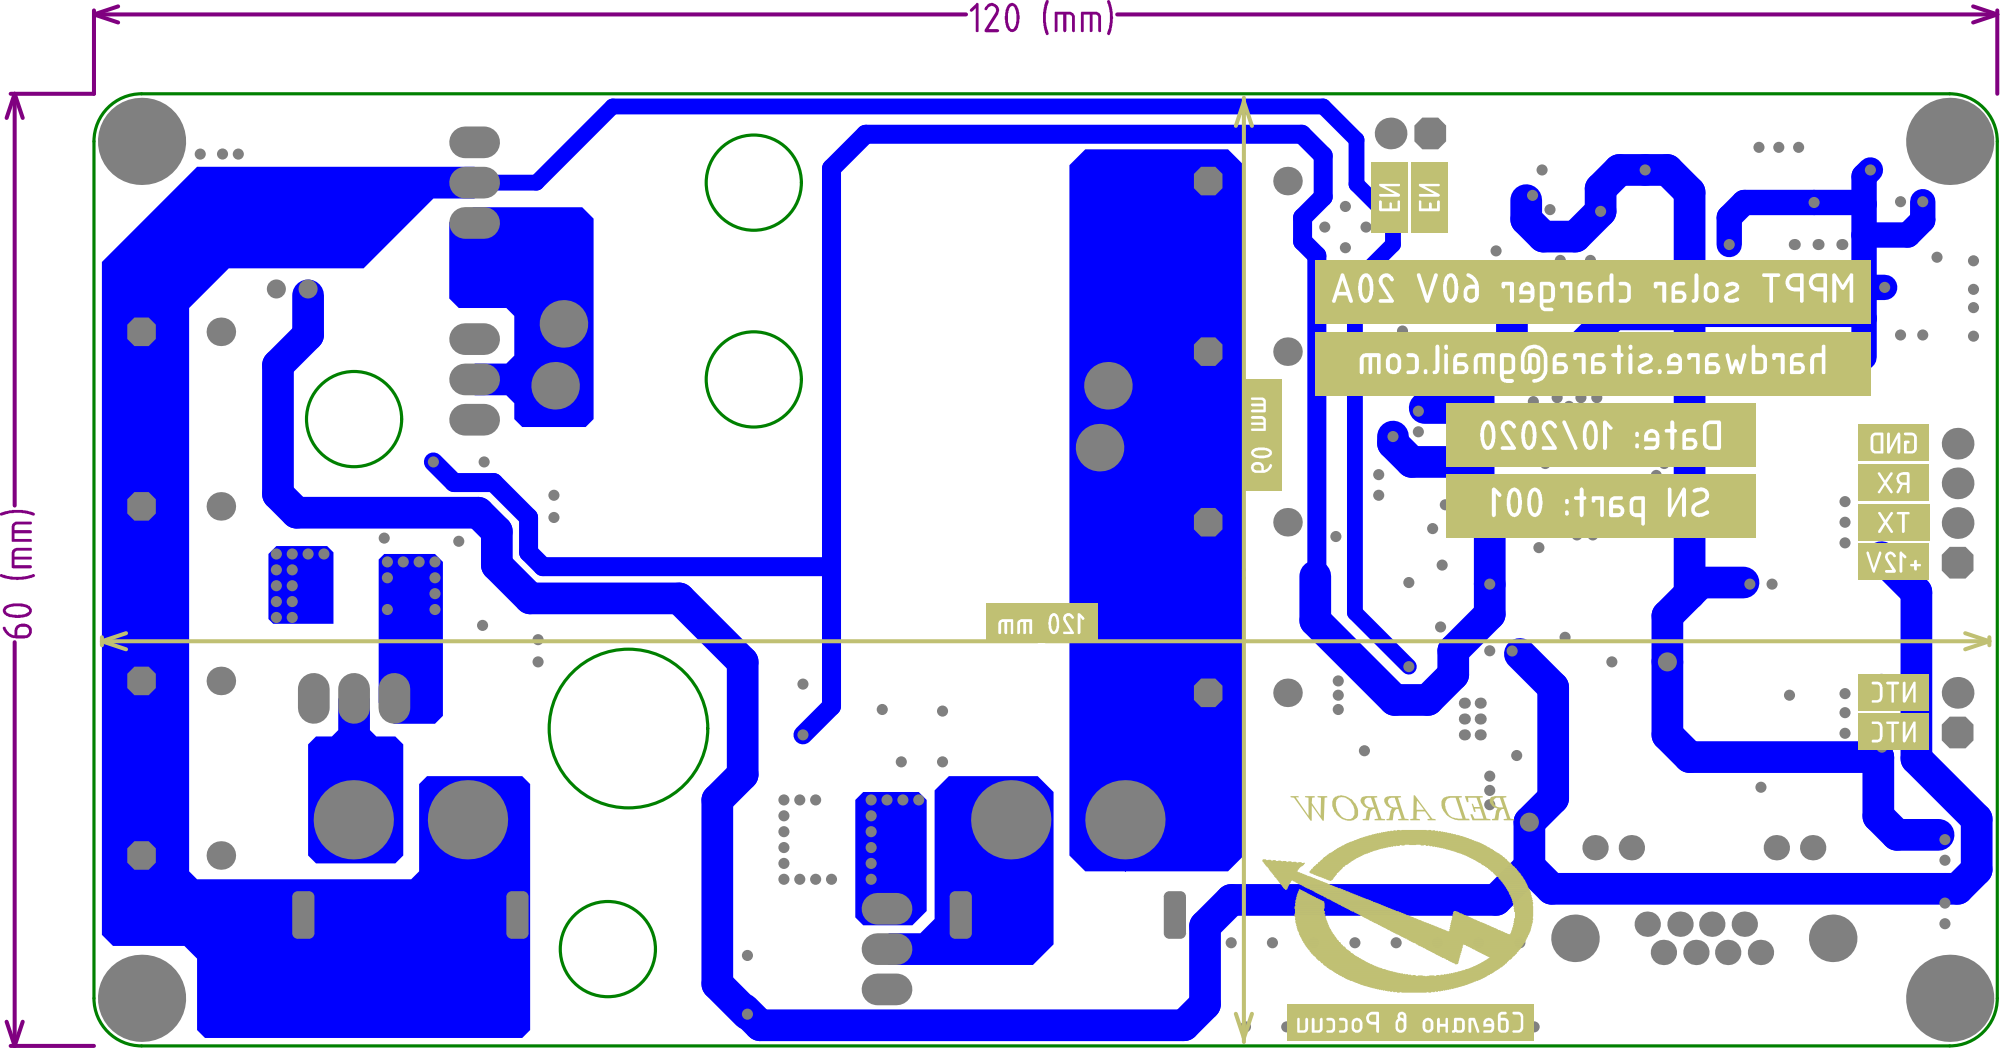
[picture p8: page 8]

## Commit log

2020-03-02 docs: Изменил используемые пины, теперь это финальная версия
2020-03-02 docs: Сгенерировал КД для производства прототипа HW: 1.00
    [BomForSolarCharger.xlsx]
2020-03-02 new: Завершил схему и трассировку ПП для версии HW: 1.00
    [ControlDSP.SchDoc, PowerConverter.SchDoc, SolarChargerMPPT.PrjPcb]
2020-03-03 new: Спроектировал корпус из алюминия под фрезеровку
    [BottomCase.SLDPRT, ISO7380-M3x6.SLDPRT, SMA.SLDPRT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]
2020-03-30 fix: Внес небольшие правки качество схемы устройства и поправил ВОМ
    [BomForSolarCharger.xlsx, ControlDSP.SchDoc, SolarChargerMPPT.PrjPcb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]
2020-03-31 docs: Преобразовал репозиторий чисто в HW, а FW вынес в отдельный проект
    [BomForSolarCharger.xlsx, BottomCase.SLDPRT, ControlDSP.SchDoc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]
2020-04-03 docs: Обновил описание и добавил фото последней версии контроллера
2020-05-06 refactor: Изменил структуру имен всех файлов и поправил gitignore
    [BottomCase.SLDPRT, ISO7380-M3x6.SLDPRT, SMA.SLDPRT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]
2020-05-07 fix: Исправил ошибку распиновки на разъеме RJ-45
    Из-за ошибки в футпринте разъема RJ-45 на плате появилась
    ошибка: у зеленого светодиод (ноги 9 и 10) перепутаны
    анод и катод (+ и -) и из-за этого светодиод нельзя зажечь.
    Исправил данную ошибку на футпринте в библиотеке и перенес
    изменения в проект.
    Обновил КД (схему и gerber) с учетом внесенного исправления
    [dsp-control.SchDoc, solar-charger-2420.PrjPcb]
2020-05-13 docs: Добавил в описание проекта ссылку на встроенное ПО
2020-08-05 refactor: Изменил неймин папки с проектом AD
    [dsp-control.SchDoc, power-converter.SchDoc, solar-charger-2420.PrjPcb]
2020-08-05 docs: Обновил пути до игнорируемых папок в AD
2020-09-18 refactor: Слил 2 репозитория (firm и hard) в один общий для упрощения поддержки версий
    [BottomCase.SLDPRT, ISO7380-M3x6.SLDPRT, SMA.SLDPRT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]
2020-09-18 docs: Добавил файл с явным указанием языка проекта
    [BottomCase.SLDPRT, ISO7380-M3x6.SLDPRT, SMA.SLDPRT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]
2020-09-18 docs: Обновил описание проекта согласно актуальным данным
2020-10-12 new: Завершил принципиальную схему для 2-й версии железа
    [dsp-control.SchDoc, dsp.SchDoc, power-converter.SchDoc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]
2020-10-29 docs: Сформировал финальную версию pinout для F334
2020-10-29 docs: Удалили лишние мануалы и добавил DIV24 на pinout
2020-10-29 docs: Обновил пути до папок мусорок у AD
2020-10-29 new: Завершил трассировку печатной платы для 2-й версии
    [dsp.SchDoc, power-converter.SchDoc, solar-charger-2420.PrjPcb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]
2020-10-29 docs: Сгенерировал КД для 2-й версии: gerber, P&P, BOM, 3D модель, схема
    [bom.xlsx]
2020-11-13 fix: Исправил подключение ОУ в цепи измерения входного тока
    Т.к. ток протекает через нагрузку и затем втекает обратно в панель,
    то потенциал GND выше, чем потенциал PV-, а следовательно нужно
    поменять местами инвертированный и неинвертированный входы ОУ
    [power-converter.SchDoc, solar-charger-2420.PrjPcb]
2020-11-30 fix: Добавил лого на плату, увеличил размер шрифтов на шелке
    [solar-charger-2420.PrjPcb]
2020-12-23 new: Update mechanical project to case version HW 2.0
    [BottomCase.SLDPRT, TopCase.SLDPRT, bottom-case.SLDPRT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]
2021-04-11 refactor: Move firmware project into a separate repository
    [ISO7380-M3x6.SLDPRT, SMA.SLDPRT, bom.xlsx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]
2021-04-12 docs: Update description for MPPT HW project
    [dsp.SchDoc, power-converter.SchDoc, solar-charger-2420.PrjPcb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]
